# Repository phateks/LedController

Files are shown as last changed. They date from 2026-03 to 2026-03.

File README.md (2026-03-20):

# LED Controller (ESP32-C3-Mini)

<table>
	<tr>
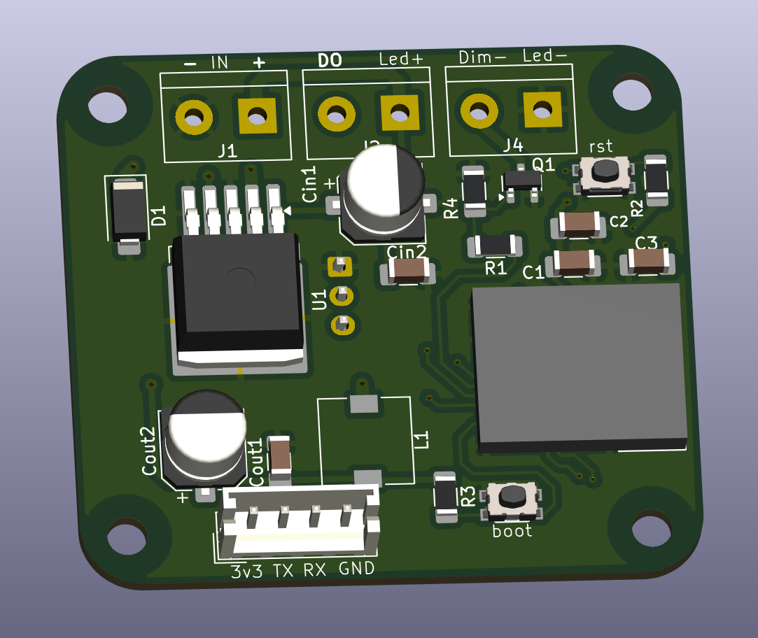
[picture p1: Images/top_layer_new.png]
PCB Top
		<td></td>
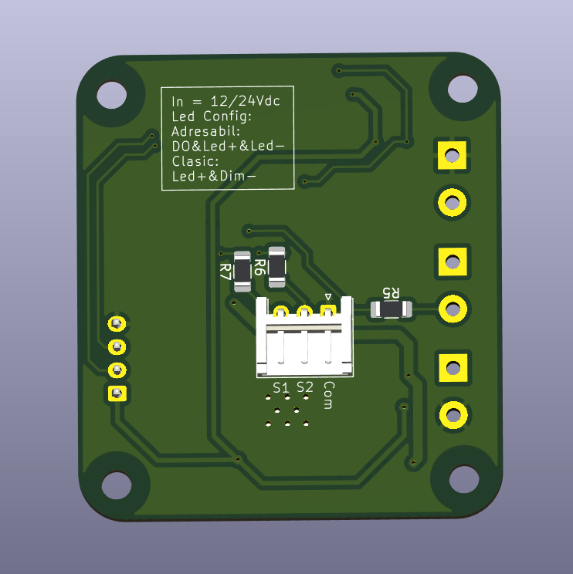
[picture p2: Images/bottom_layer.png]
PCB Bottom
		<td></td>
	</tr>
</table>

## Power
- Input: 12 or 24 VDC on J1 connector

## Connections for Digital LED
- DO (DATA) 
- LED+ = VCC
- LED- = GND

## Connections for Classic LED
- LED+ = VCC
- Dim- = GND

## External Switch (Momentary)

- S1 - Dim down
- S2 - Dim up
- Com - Second connection on the switch (common for both)

## GPIO Config

- IO4: DATA LED
- IO5: PWM LED
- IO6: Dim Up
- IO7: Dim Down
- TXD0/RXD0: 
- EN: reset/enable
- BOOT: bootloader (IO09)

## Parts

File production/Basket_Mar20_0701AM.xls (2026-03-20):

SHOPPING BASKET
This is not an invoice
20-Mar-26 07:01:44
 | Mouser No | Mfr. No | Manufacturer | Customer No | Description | RoHS | Lifecycle | Order Qty. | Price (RON) | Ext.: (RON)
1 | 611-KMR211G-LFS | KMR211G LFS | C&K Switches |  | Tactile Switches Micro Mini SMT Top Actuat Tact Switch | RoHS Compliant |  | 10 | 2,04 RON | 20,40 RON
2 | 356-ESP32C3MINI1N4X | ESP32-C3-MINI-1-N4X | Espressif |  | Multiprotocol Modules SMD module, ESP32-C3FH4X, Chip Revision v1.1 or above, PCB antenna, -40 C +85 C | RoHS Compliant | New Product | 5 | 13,73 RON | 68,65 RON
3 | 926-LM2596S-3.3/NOPB | LM2596S-3.3/NOPB | Texas Instruments |  | Switching Voltage Regulators 150 KHZ 3A STEP-DOWN VLTG REG A 926-LM25 A 926-LM2596SX33NOPB | RoHS Compliant By Exemption |  | 5 | 30,13 RON | 150,65 RON
4 | 821-SS34ALH | SS34ALH | Taiwan Semiconductor |  | Schottky Diodes & Rectifiers 3A, 40V, Schottky Rectifier | RoHS Compliant By Exemption |  | 5 | 2,33 RON | 11,65 RON
5 | 871-B82472P6333M000 | B82472P6333M000 | TDK |  | Power Inductors - SMD SMT-INDUCTOR 7X7 33.0UH1.15A,AECQ200 | RoHS Compliant |  | 5 | 6,29 RON | 31,45 RON
6 | 81-GCM319R71H104KA7J | GCM319R71H104KA37J | Murata |  | Multilayer Ceramic Capacitors MLCC - SMD/SMT 0.1 uF 50 VDC 10% 1206 X7R AEC-Q200 | RoHS Compliant | NRND | 15 | 0,568 RON | 8,52 RON
7 | 581-12065C106KAT2A | 12065C106KAT2A | KYOCERA AVX |  | Multilayer Ceramic Capacitors MLCC - SMD/SMT 10UF 50V 10% 1206 | RoHS Compliant |  | 5 | 3,59 RON | 17,95 RON
8 | 667-EEE-FT1V331GP | EEE-FT1V331GP | Panasonic |  | Aluminium Electrolytic Capacitors - SMD 35volts 330uf | RoHS Compliant |  | 5 | 4,20 RON | 21,00 RON
9 | 667-EEE-FT0J331AL | EEE-FT0J331AL | Panasonic |  | Aluminium Electrolytic Capacitors - SMD 6.3VDC 330uF 20% 6x6mm AEC-Q200 | RoHS Compliant |  | 5 | 3,07 RON | 15,35 RON
10 | 581-KAM31GR71H105KU | KAM31GR71H105KU | KYOCERA AVX |  | Multilayer Ceramic Capacitors MLCC - SMD/SMT 50V 1uF X7R 1206 10% AEC-Q200 | RoHS Compliant |  | 5 | 1,73 RON | 8,65 RON
11 | 660-SG73S2BTTD221G | SG73S2BTTD221G | KOA Speer |  | Thick Film Resistors - SMD 0.33W 220ohm 2% 200ppm Anti-Surge | RoHS Compliant By Exemption |  | 5 | 1,57 RON | 7,85 RON
12 | 71-CRMA1206AF10K0DKF | CRMA1206AF10K0DKEF | Vishay |  | Thick Film Resistors - SMD 0.30W 10Kohm .5% AEC-Q200 | RoHS Compliant By Exemption |  | 15 | 1,44 RON | 21,60 RON
13 | 71-RCC1206470RFKEA | RCC1206470RFKEA | Vishay |  | Thick Film Resistors - SMD 470ohms 1% 100ppm | RoHS Compliant By Exemption |  | 5 | 1,08 RON | 5,40 RON
14 | 603-RT1206FRE13100RL | RT1206FRE13100RL | YAGEO |  | Thin Film Resistors - SMD 100 ohm 1% 50 ppm Thin Film | RoHS Compliant By Exemption |  | 10 | 0,322 RON | 3,22 RON
By submitting your order you agree to these terms and conditions. (https://ro.mouser.com/saleterms) |  |  |  |  |  |  |  |  | Merchandise: | 392,34 RON
Prices are reflected at the date and time shown. |  |  |  |  |  |  |  |  | Delivery Charge: | 0,00 RON

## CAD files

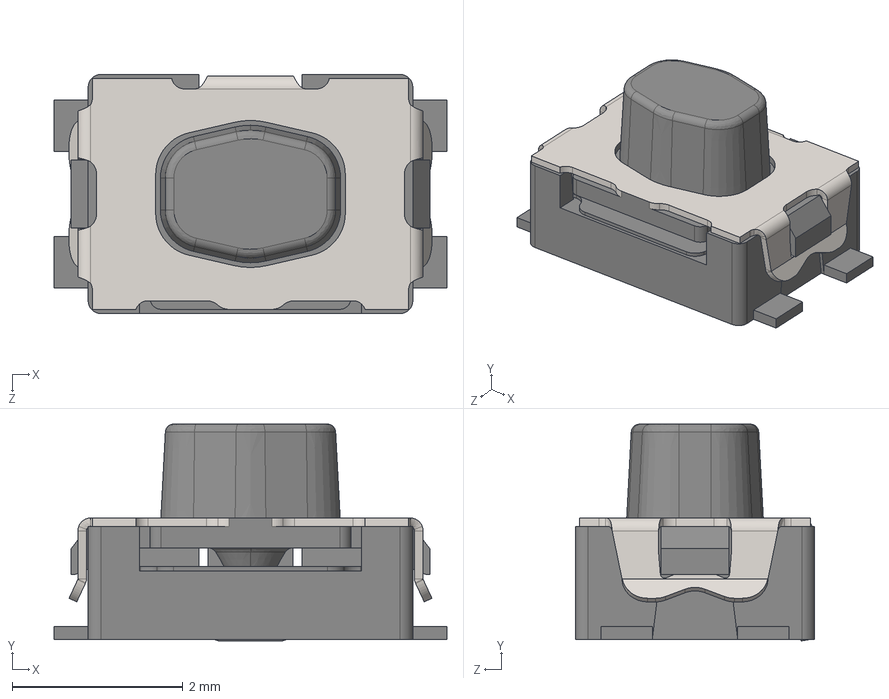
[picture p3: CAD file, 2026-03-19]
Parts/KMR211G_LFS/3D/KMR211G_LFS.stp
4.60 x 2.54 x 2.80 mm

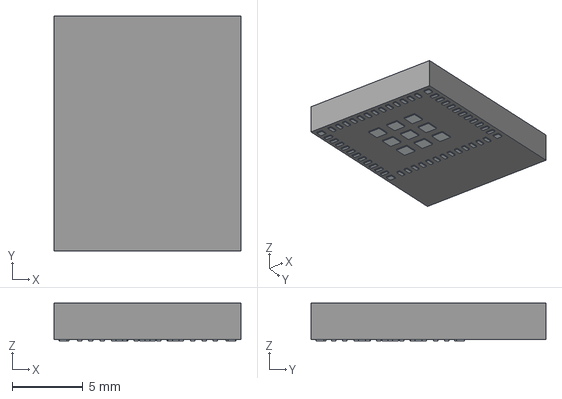
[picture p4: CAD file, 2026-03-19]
Parts/LIB_ESP32-C3-MINI-1-N4X/ESP32-C3-MINI-1-N4X/3D/ESP32-C3-MINI-1-N4X.stp
13.2 x 16.6 x 2.65 mm
Pins

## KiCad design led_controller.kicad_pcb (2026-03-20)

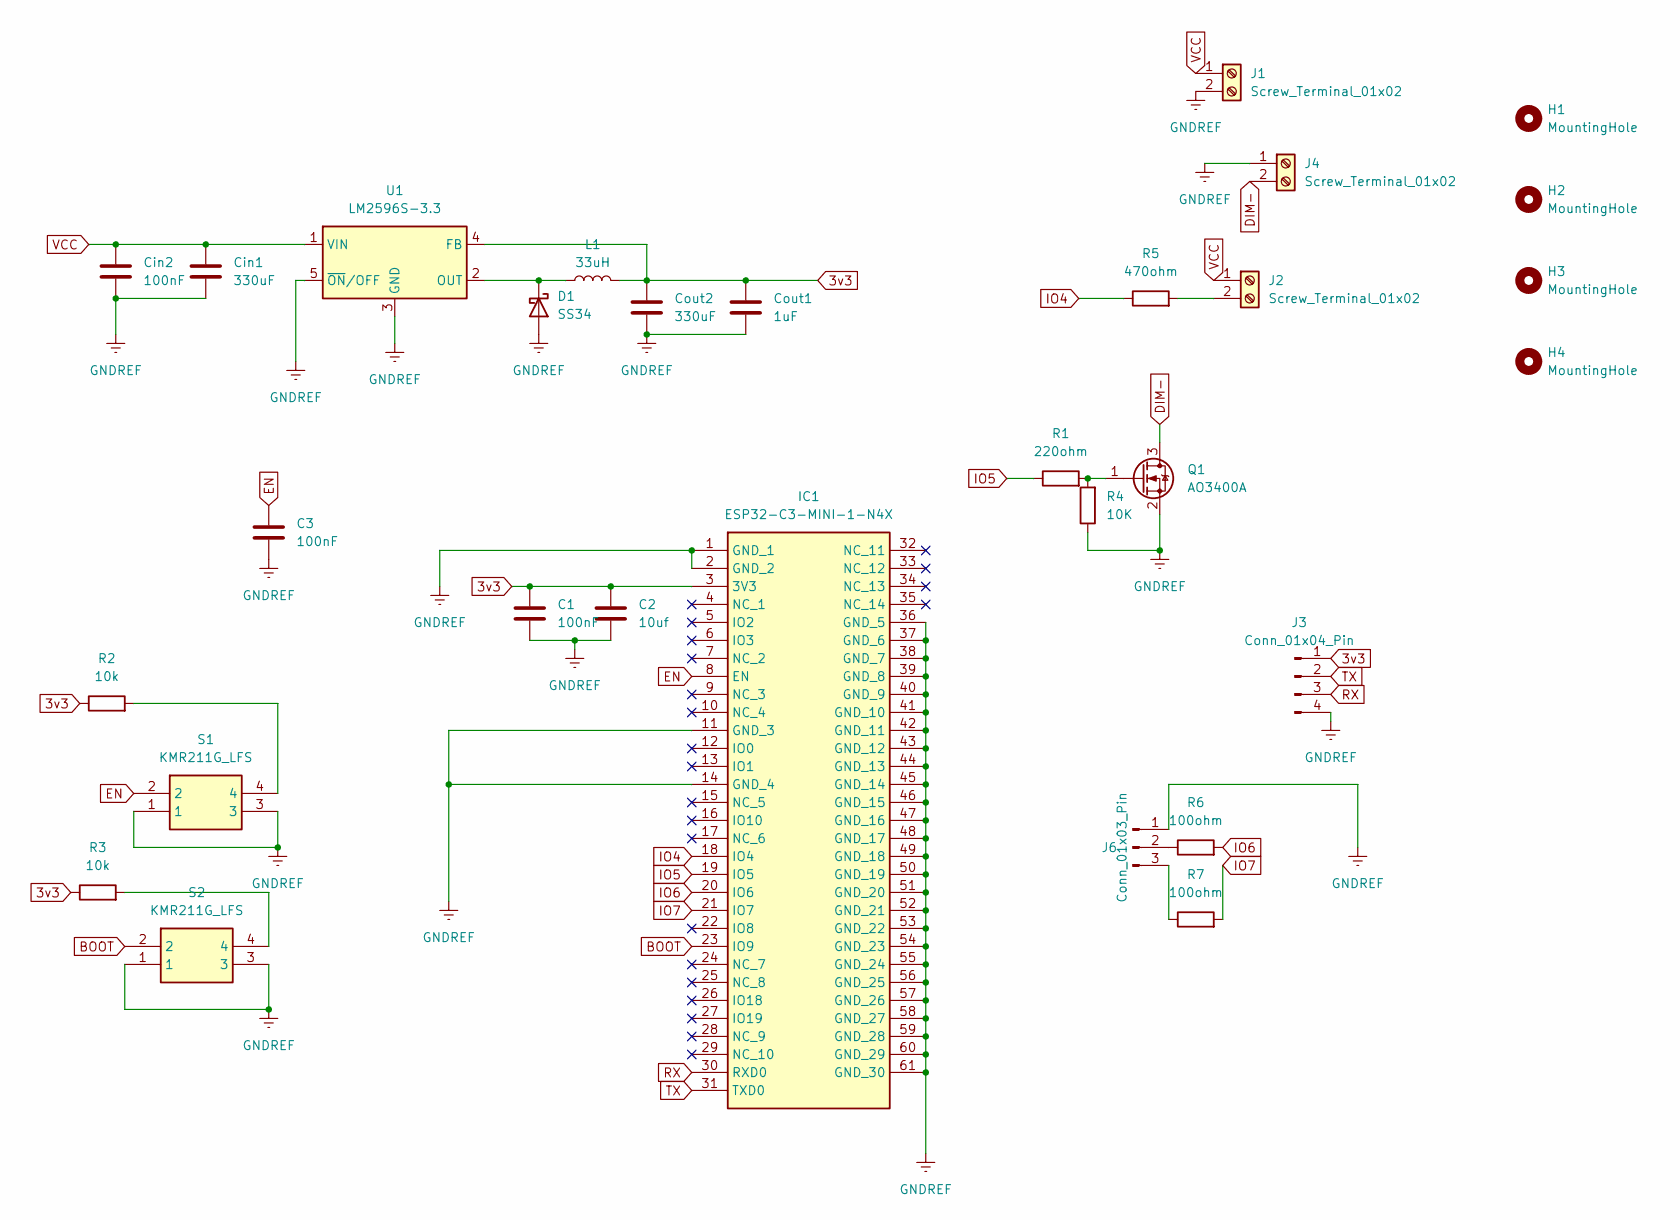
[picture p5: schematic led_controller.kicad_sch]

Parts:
C1, C3: 100nF
C2: 10uf; C_1206_3216Metric_Pad1.33x1.80mm_HandSolder
Cin1: 330uF; CP_Elec_8x10
Cin2: 100nF
Cout1: 1uF; C_1206_3216Metric_Pad1.33x1.80mm_HandSolder
Cout2: 330uF; CP_Elec_6.3x5.8
D1: SS34; D_SMA
H1, H2, H3, H4: MountingHole; MountingHole_3.2mm_M3
IC1: ESP32-C3-MINI-1-N4X; ESP32C3MINI1N4X; Manufacturer_Part_Number ESP32-C3-MINI-1-N4X
J1, J2, J4: Screw_Terminal_01x02; TerminalBlock_bornier-2_P5.08mm
J3: Conn_01x04_Pin; JST_EH_B4B-EH-A_1x04_P2.50mm_Vertical
J6: Conn_01x03_Pin; JST_EH_S3B-EH_1x03_P2.50mm_Horizontal
L1: 33uH; L_7.3x7.3_H4.5
Q1: AO3400A; SOT-23
R1: 220ohm
R2, R3: 10k
R4: 10K
R5: 470ohm
R6, R7: 100ohm
S1, S2: KMR211G_LFS; KMR_2; Manufacturer_Part_Number KMR211G LFS; Mouser Part Number 611-KMR211G-LFS
U1: LM2596S-3.3; TO-263-5_TabPin3

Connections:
3v3: C1.1, C2.1, Cout1.1, Cout2.1, IC1.3 (3V3), J3.1, L1.2, R2.1, R3.1, U1.4 (FB)
BOOT: IC1.23 (IO9), S2.2
DIM-: J4.2, Q1.3 (D)
EN: C3.1, IC1.8 (EN), S1.2
GNDREF: C1.2, C2.2, C3.2, Cin1.2, Cin2.2, Cout1.2, Cout2.2, D1.2 (A), IC1.1 (GND_1), IC1.2 (GND_2), IC1.11 (GND_3), IC1.14 (GND_4), IC1.36 (GND_5), IC1.37 (GND_6), IC1.38 (GND_7), IC1.39 (GND_8), IC1.40 (GND_9), IC1.41 (GND_10), IC1.42 (GND_11), IC1.43 (GND_12), IC1.44 (GND_13), IC1.45 (GND_14), IC1.46 (GND_15), IC1.47 (GND_16), IC1.48 (GND_17), IC1.49 (GND_18), IC1.50 (GND_19), IC1.51 (GND_20), IC1.52 (GND_21), IC1.53 (GND_22), IC1.54 (GND_23), IC1.55 (GND_24), IC1.56 (GND_25), IC1.57 (GND_26), IC1.58 (GND_27), IC1.59 (GND_28), IC1.60 (GND_29), IC1.61 (GND_30), J1.2, J3.4, J4.1, J6.1, Q1.2 (S), R4.1, S1.1, S1.3, S2.1, S2.3, U1.3 (GND), U1.5 (~ON/OFF)
IO4: IC1.18 (IO4), R5.1
IO5: IC1.19 (IO5), R1.1
IO6: IC1.20 (IO6), R6.2
IO7: IC1.21 (IO7), R7.2
unnamed: D1.1 (K), L1.1, U1.2 (OUT)
unnamed: J2.2, R5.2
unnamed: J6.2, R6.1
unnamed: J6.3, R7.1
unnamed: Q1.1 (G), R1.2, R4.2
unnamed: R2.2, S1.4
unnamed: R3.2, S2.4
RX: IC1.30 (RXD0), J3.3
TX: IC1.31 (TXD0), J3.2
VCC: Cin1.1, Cin2.1, J1.1, J2.1, U1.1 (VIN)

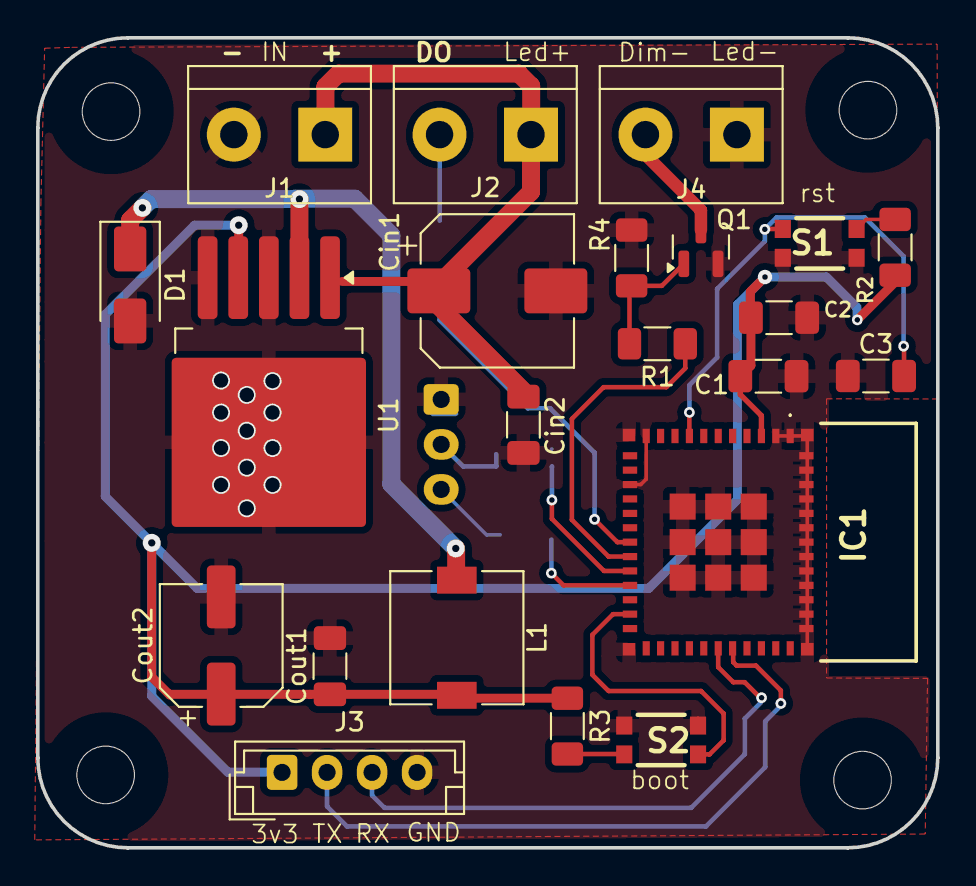
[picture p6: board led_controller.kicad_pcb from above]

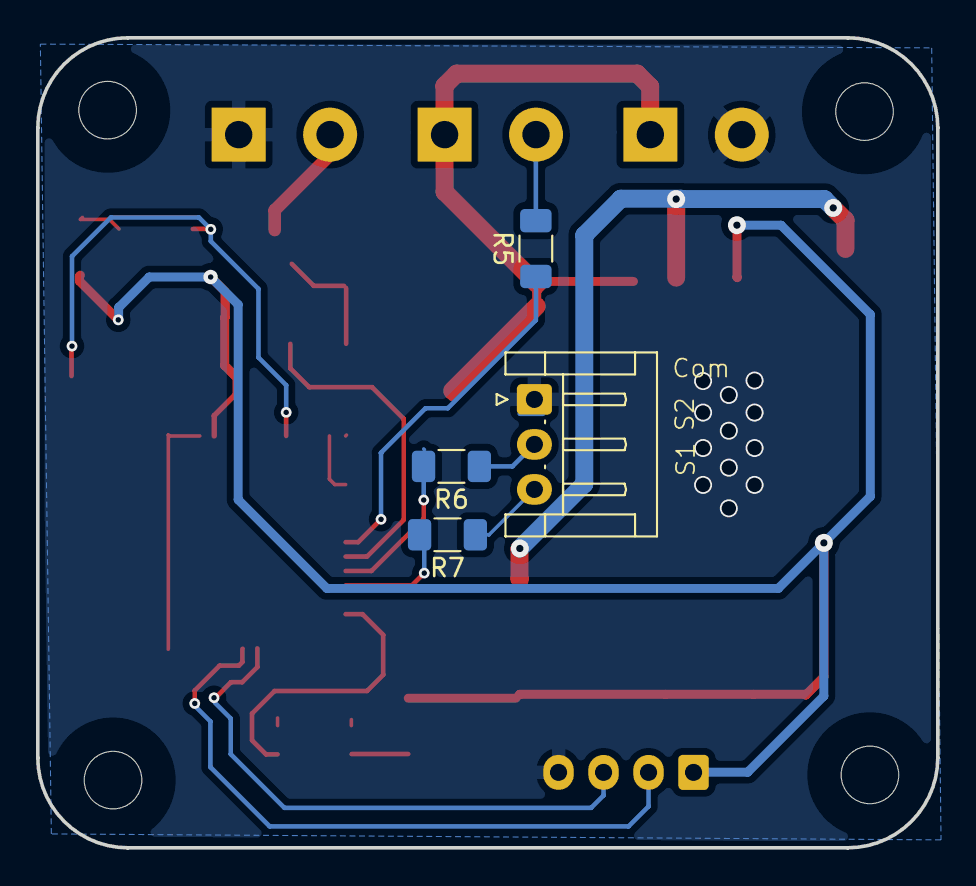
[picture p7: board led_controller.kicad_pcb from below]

Board: 2 copper layers, 50.0 x 45.0 mm, 30 parts (4 on the bottom side), 19 nets.

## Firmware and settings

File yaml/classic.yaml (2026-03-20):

esphome:
  name: led-controller-classic
  friendly_name: LED Controller Classic

esp32:
  board: esp32-c3-devkitm-1
  variant: esp32c3
  framework:
    type: arduino

logger:
api:
ota:

wifi:
  ssid: !secret wifi_ssid
  password: !secret wifi_password

output:
  - platform: ledc
    pin: GPIO5
    id: pwm_out
    frequency: 1000Hz

light:
  - platform: monochromatic
    name: "Classic LED"
    output: pwm_out
    id: classic_led

binary_sensor:
  - platform: gpio
    id: dim_down_btn
    pin:
      number: GPIO6
      mode: INPUT_PULLUP
      inverted: true
    on_click:
      min_length: 50ms
      max_length: 400ms
      then:
        - light.toggle: classic_led
    on_press:
      then:
        - delay: 600ms
        - if:
            condition:
              binary_sensor.is_on: dim_down_btn
            then:
              - while:
                  condition:
                    binary_sensor.is_on: dim_down_btn
                  then:
                    - light.dim_relative:
                        id: classic_led
                        relative_brightness: -5%
                        transition_length: 0.1s
                    - delay: 0.1s

  - platform: gpio
    id: dim_up_btn
    pin:
      number: GPIO7
      mode: INPUT_PULLUP
      inverted: true
    on_click:
      min_length: 50ms
      max_length: 400ms
      then:
        - light.toggle: classic_led
    on_press:
      then:
        - delay: 600ms
        - if:
            condition:
              binary_sensor.is_on: dim_up_btn
            then:
              - while:
                  condition:
                    binary_sensor.is_on: dim_up_btn
                  then:
                    - light.dim_relative:
                        id: classic_led
                        relative_brightness: 5%
                        transition_length: 0.1s
                    - delay: 0.1s

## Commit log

2026-03-20 Add initial README for LED Controller project
    Added detailed information about the LED controller, including power requirements, connections, external switch configuration, and GPIO settings.
2026-03-20 Update README with PCB images
2026-03-20 Update PCB top image in README
2026-03-20 kicad10 and modified antenna
    [Basket_Mar20_0701AM.xls, led_controller.kicad_pcb, led_controller.kicad_sch]
